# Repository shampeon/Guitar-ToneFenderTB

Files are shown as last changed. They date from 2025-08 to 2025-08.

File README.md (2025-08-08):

A small PCB for the Fender AB763 treble and bass tone stack. Inspired by Tristan Collins's [Bandmaster PCB](https://github.com/tristancollins/Guitar-ToneBandmaster), with the same dimensions and for the PCB and mounting holes, and created in KiCad 9.

# Components and their values

* R1: 100k (tone slope resistor, 0.5W or greater)
* R2: 6.8k (mid resistor, 0.5W or greater)
* C1: 250pF (treble capacitor, 400V or greater)
* C2: 100nF/0.1uF (bass capacitor, 400V or greater), has through holes for axial or 5mm radial caps
* C3: 4.7nF/0.0047uF (mid capacitor, 400V or greater)
* J1, J2: 2 pin screw terminal, 5mm spacing
* RV1, RV2: 3 pin screw terminal, 5mm spacing

You can adjust the values of the components to change the behavior of the tone stack. Select the Fender Treble-Bass tonestack at [Yet Another Tonestack Calculator](https://tonestack.yuriturov.com) to compare the frequency response to the standard values here.

Rob Robinette has a great [page on how the TMB tone stack works](https://robrobinette.com/How_The_TMB_Tone_Stack_Works.htm).

# Fabricating the PCB

The 53mm x 45mm PCB can be manufactured by any of the online PCB fabrication sites, like [PCBWay](https://pcbway.com) or [JLCPCB](https://jlcpcb.com/). I use PCBWay, so the back text `WayWayWay` will be converted to the PCBWay product number when it is manufactured. You may want to modify this if you use another manufacturer.

A Gerber file ZIP is included in the repository, generated using the PCBWay plugin for KiCad 9.

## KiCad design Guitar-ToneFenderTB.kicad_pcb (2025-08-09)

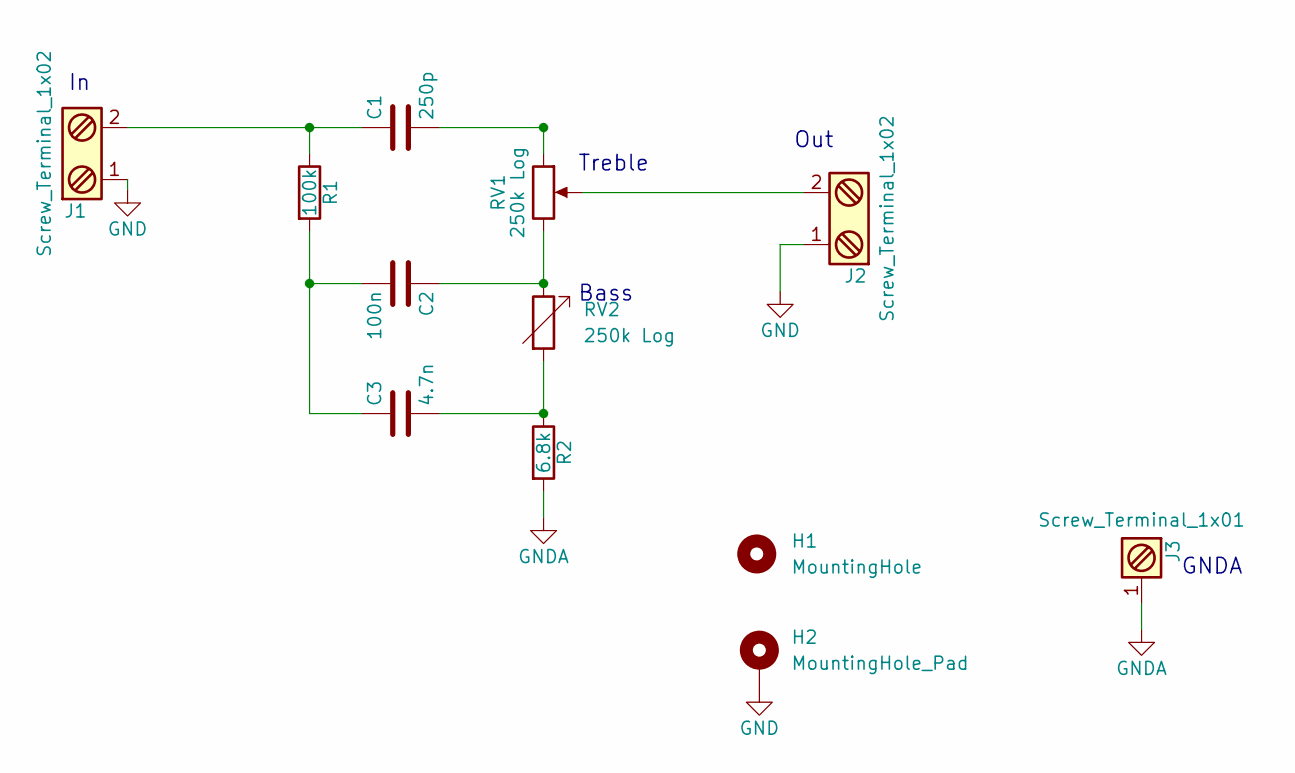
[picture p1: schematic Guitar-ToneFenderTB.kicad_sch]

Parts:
C1: 250p; C_Disc_D7.5mm_W5.0mm_P7.50mm
C2: 100n; C_Axial_L22.0mm_D9.5mm_P27.50mm_Horizontal
C3: 4.7n; C_Axial_L12.0mm_D6.5mm_P15.00mm_Horizontal
H1: MountingHole; MountingHole_3.2mm_M3
H2: MountingHole_Pad; MountingHole_3.2mm_M3_Pad
J1, J2: Screw_Terminal_1x02; PhoenixContact_MCV_1,5_2-G-5.08_1x02_P5.08mm_Vertical
J3: Screw_Terminal_1x01; SolderWire-0.75sqmm_1x01_D1.25mm_OD2.3mm
R1: 100k; R_Axial_DIN0414_L11.9mm_D4.5mm_P15.24mm_Horizontal
R2: 6.8k; R_Axial_DIN0414_L11.9mm_D4.5mm_P15.24mm_Horizontal
RV1: 250k Log; PhoenixContact_MCV_1,5_3-G-5.08_1x03_P5.08mm_Vertical; MPN 1729131
RV2: 250k Log; PhoenixContact_MCV_1,5_3-G-5.08_1x03_P5.08mm_Vertical

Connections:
GND: H2.1, J1.1, J2.1
GNDA: J3.1, R2.2
unnamed: C1.1, J1.2, R1.1
unnamed: C1.2, RV1.1
unnamed: C2.1, RV1.3, RV2.1
unnamed: C2.2, C3.1, R1.2
unnamed: C3.2, R2.1, RV2.2
unnamed: J2.2, RV1.2

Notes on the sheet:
Treble
Out
Bass
GNDA

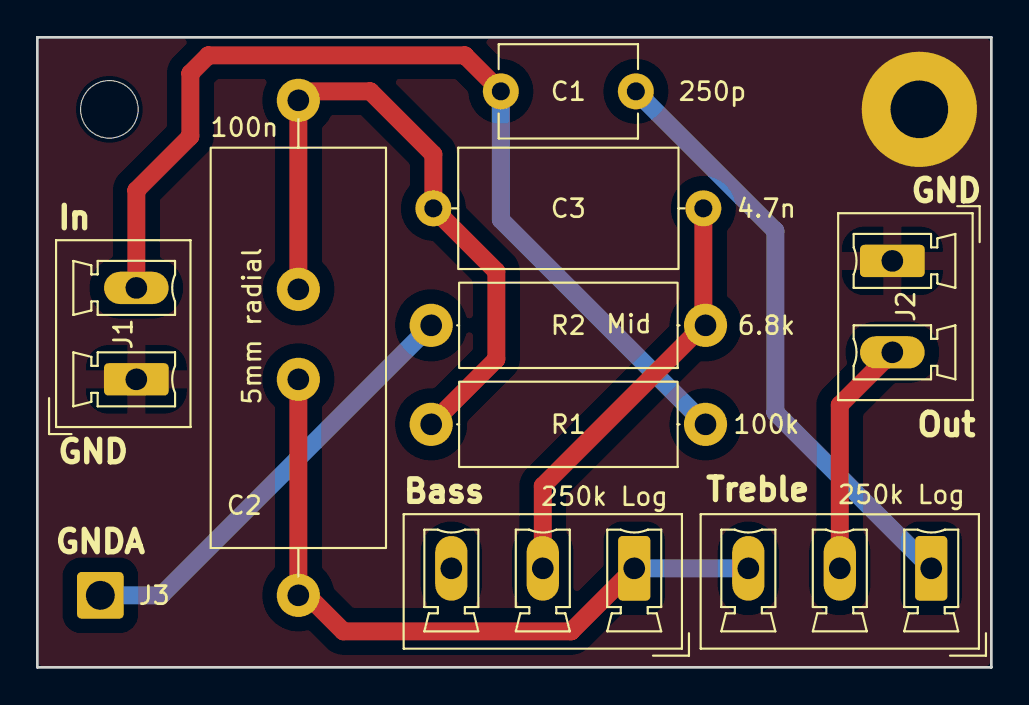
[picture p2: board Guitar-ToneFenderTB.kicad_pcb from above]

Board: 2 copper layers, 53.0 x 35.0 mm, 12 parts (0 on the bottom side), 8 nets.

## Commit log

2025-08-08 Initial checkin.
    [Guitar-ToneFenderTB.kicad_pcb, Guitar-ToneFenderTB.kicad_sch]
2025-08-08 Updated silkscreen text with C2 5mm spacing, and PCBWay product number code
    [Guitar-ToneFenderTB.kicad_pcb]
2025-08-08 Adjust placement of back silkscreen text.
    [Guitar-ToneFenderTB.kicad_pcb]
2025-08-08 Adding Gerber ZIP.
2025-08-09 Fixed error in schematic, enlarged through holes for caps.
    [Guitar-ToneFenderTB.kicad_pcb, Guitar-ToneFenderTB.kicad_sch]
